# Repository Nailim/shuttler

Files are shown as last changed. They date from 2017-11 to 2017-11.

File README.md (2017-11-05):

# shuttler
Code dump for project shuttler - https://scientiatertiidimension.blogspot.com

What was project shuttler?

A project to build a mapping drone for 3D terain reconstruction which included an autopilot build for Android phones, 360° video processing, image processing, 3D pritnting, electronics design and all other neceseties when building a drone from scratch.

More info on the project blog.

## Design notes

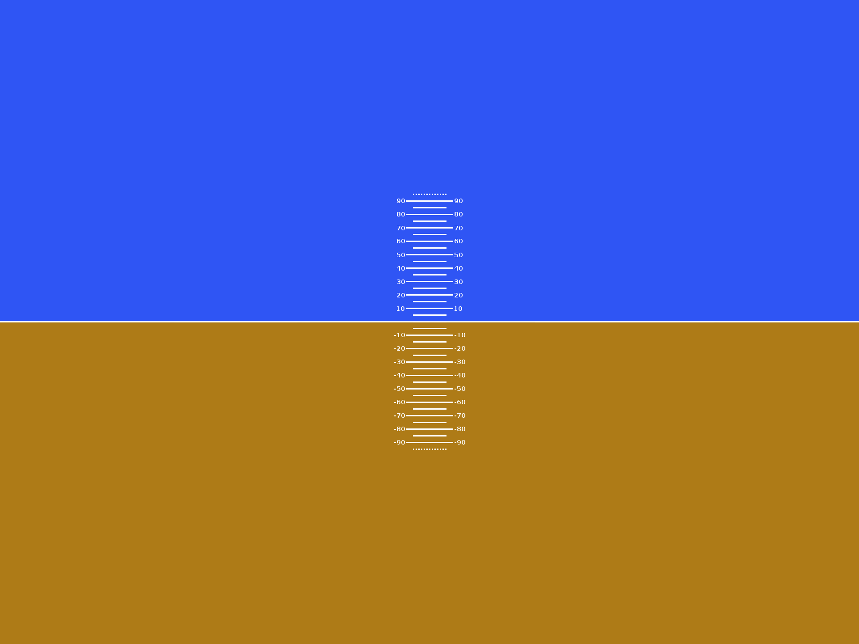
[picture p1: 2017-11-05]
Code/Python/TelemetryProcessing/telemetry2video/Attitude/resources/horizon.png

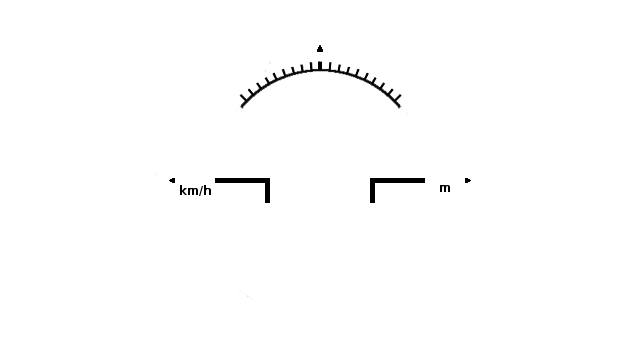
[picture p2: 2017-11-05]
Code/Python/TelemetryProcessing/telemetry2video/Attitude/resources/terrain.png

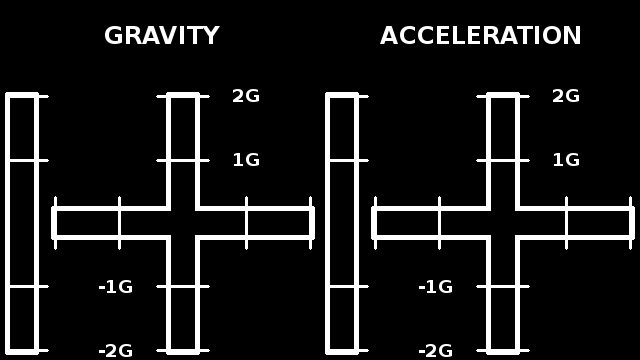
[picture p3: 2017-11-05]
Code/Python/TelemetryProcessing/telemetry2video/Acceleration/resources/controls.png

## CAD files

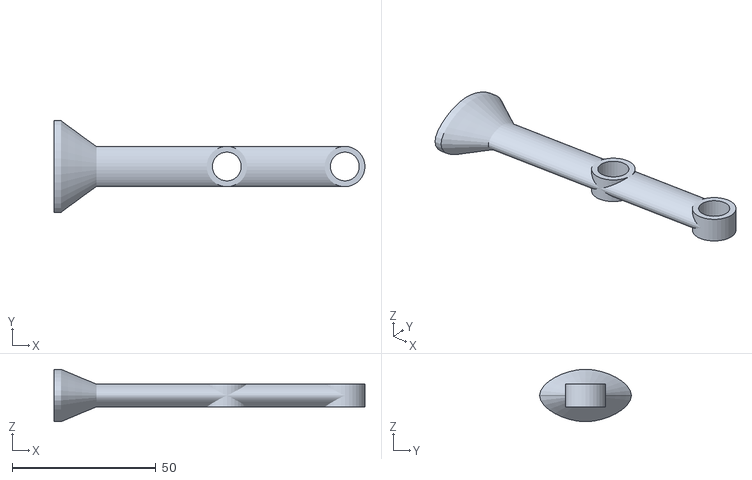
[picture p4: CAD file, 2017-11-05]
Code/Blender/CameraMountHolder/v3/CameraMountHolder_V03_repaired.stl
108.0 x 31.9 x 18.2

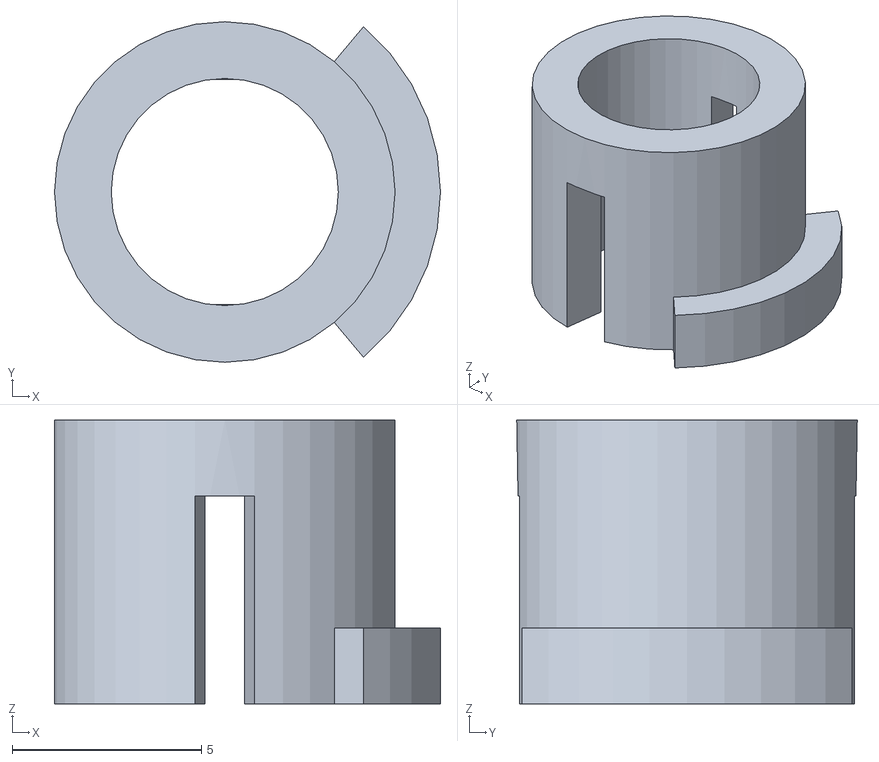
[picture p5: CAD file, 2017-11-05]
Code/Blender/PigTailJig/pigtailJig_bottom_3repared.stl
10.2 x 9.00 x 7.50

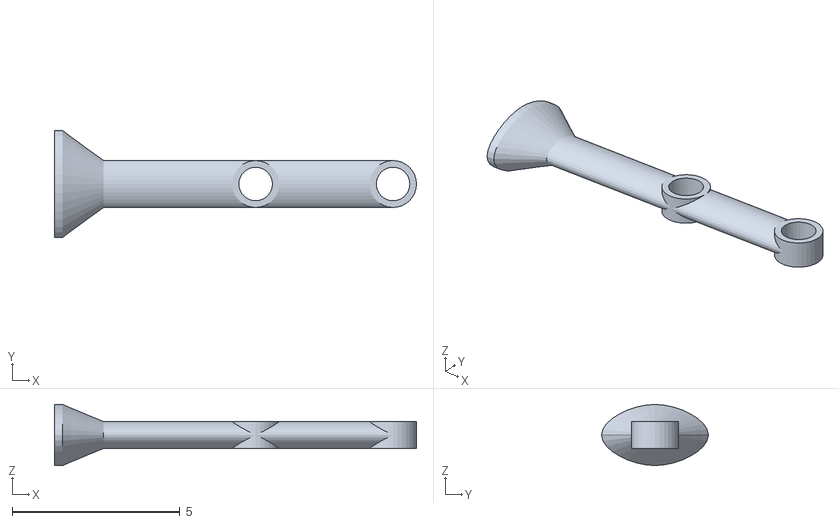
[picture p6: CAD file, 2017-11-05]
Code/Blender/CameraMountHolder/v3/CameraMountHolder_V03_raw.stl
10.8 x 3.19 x 1.82

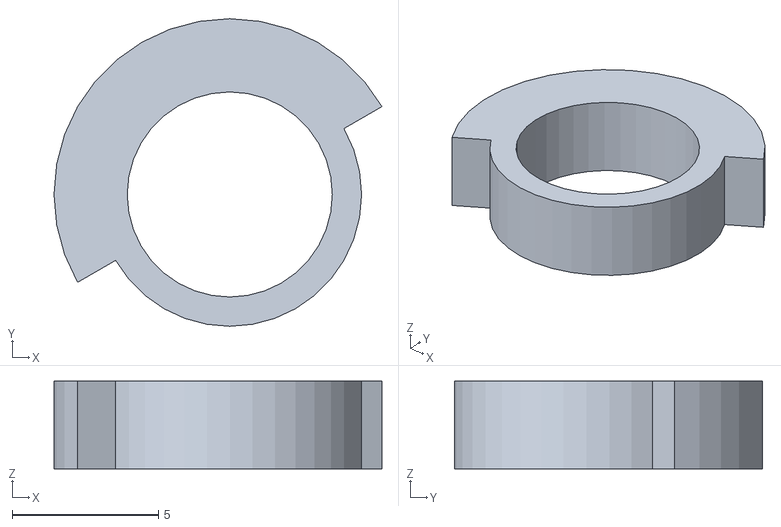
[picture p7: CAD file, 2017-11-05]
Code/Blender/PigTailJig/pigtailJig_top_3.stl
11.2 x 10.5 x 3.00

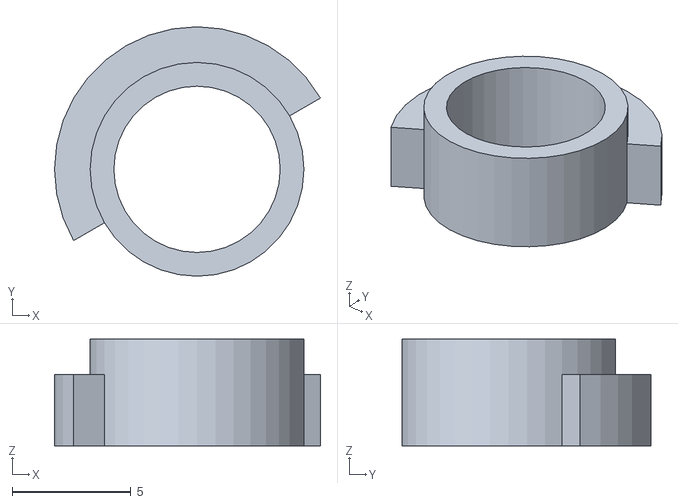
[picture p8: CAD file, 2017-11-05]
Code/Blender/PigTailJig/pigtailJig_top_2.stl
11.2 x 10.5 x 4.50

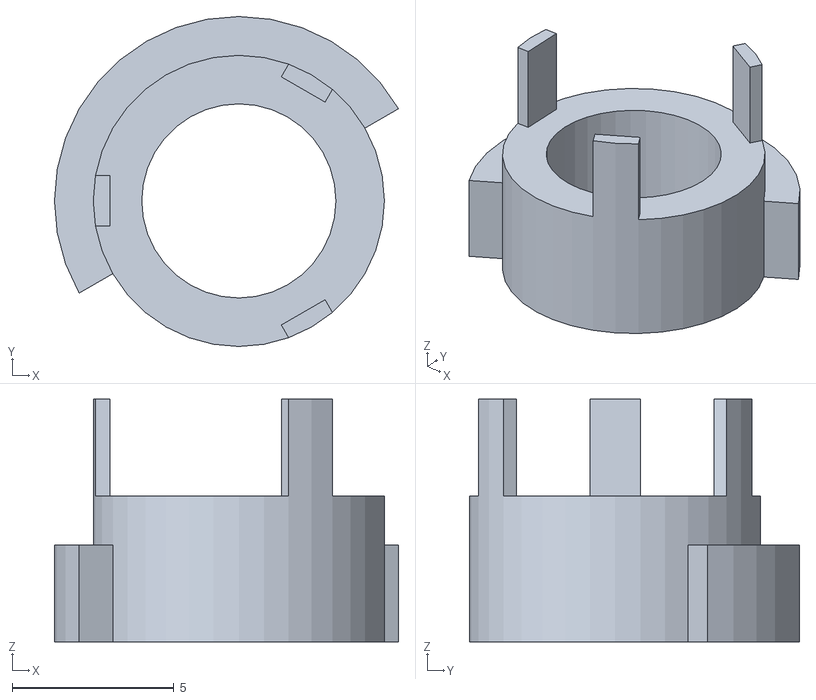
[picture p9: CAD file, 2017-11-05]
Code/Blender/PigTailJig/pigtailJig_top.stl
10.6 x 10.2 x 7.50

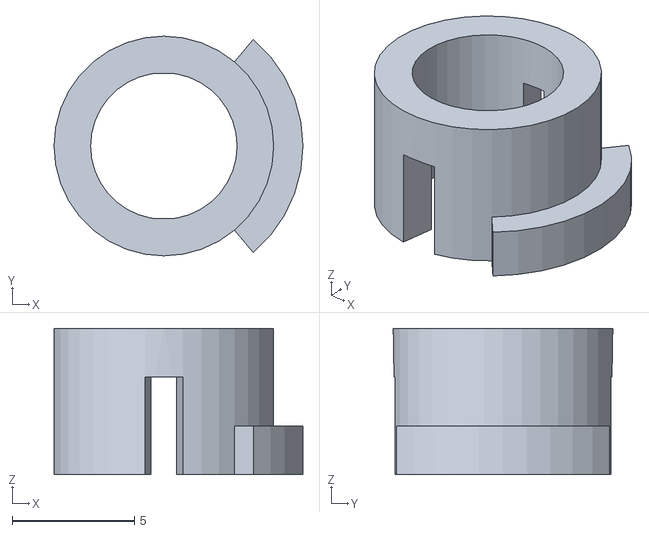
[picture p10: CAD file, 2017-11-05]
Code/Blender/PigTailJig/pigtailJig_bottom_2repared.stl
10.2 x 9.00 x 6.00

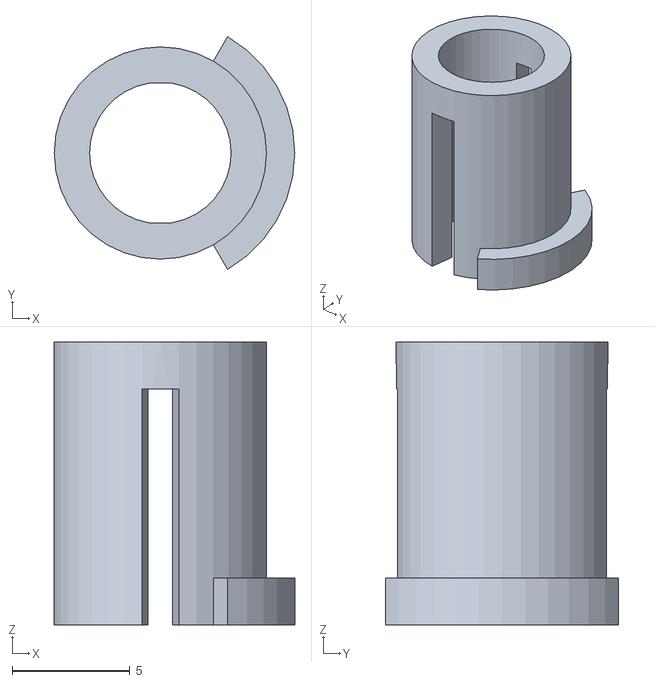
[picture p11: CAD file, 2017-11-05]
Code/Blender/PigTailJig/pigtailJig_bottom_2_repaired.stl
10.2 x 9.87 x 12.0

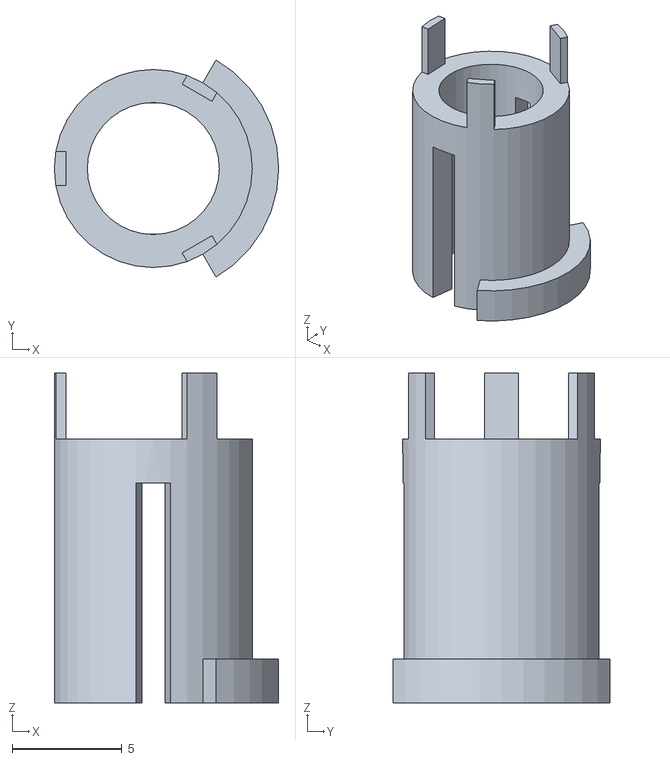
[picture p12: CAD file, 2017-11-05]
Code/Blender/PigTailJig/pigtailJig_bottom.stl
10.2 x 9.87 x 15.0

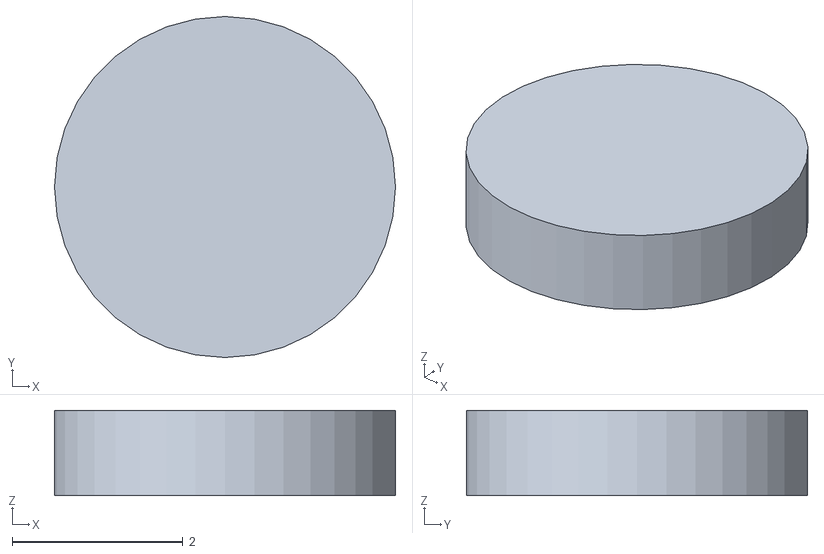
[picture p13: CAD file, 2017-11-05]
Code/Blender/PigTailJig/filler.stl
4.00 x 4.00 x 1.00

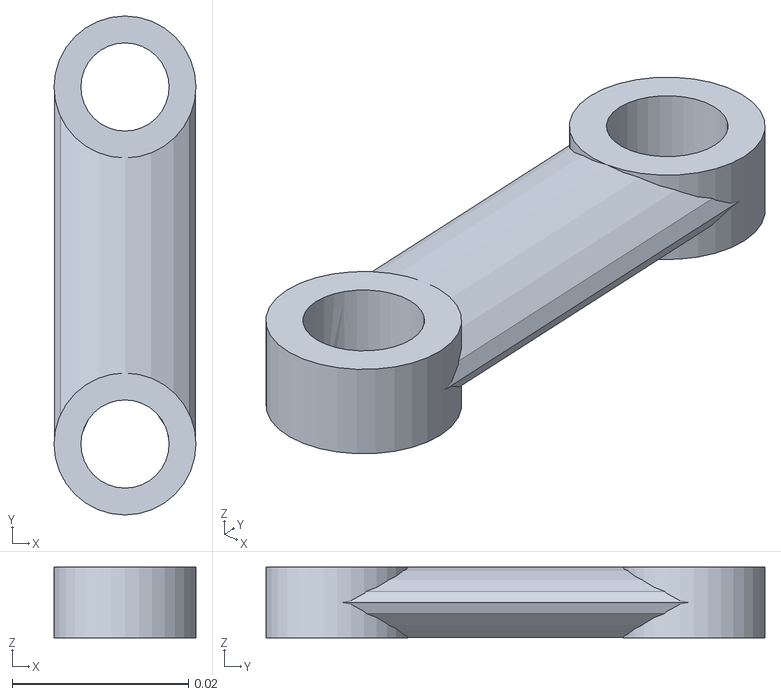
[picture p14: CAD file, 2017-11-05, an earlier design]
Code/Blender/CameraMountHolder/v1/CameraMountHolder_V01_part.stl
0.0161 x 0.0566 x 0.008

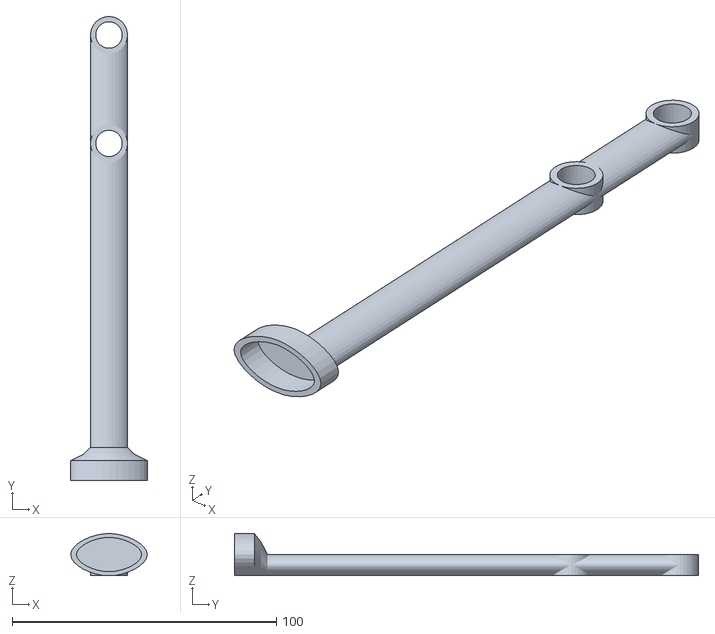
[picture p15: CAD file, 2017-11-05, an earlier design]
Code/Blender/CameraMountHolder/v2/CameraMountHolder_V02__part.stl
29.0 x 175.5 x 15.9

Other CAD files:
Code/Blender/PigTailJig/pigtailJig_top_2_repaired.stl
Code/Blender/PigTailJig/pigtailJig_top_3repared.stl
Code/Blender/PigTailJig/pigtailJig_top_repared.stl
Code/Blender/PigTailJig/pigtailJig_bottom_3.stl
Code/Blender/PigTailJig/pigtailJig_bottom_2.stl
Code/Blender/PigTailJig/pigtailJig_bottom_repared.stl
Code/Blender/CameraMountHolder/v1/CameraMountHolder_V01.blend
Code/Blender/CameraMountHolder/v1/CameraMountHolder_V01_part.blend
Code/Blender/CameraMountHolder/v1/CameraMountHolder_V01_part_ready.stl
Code/Blender/CameraMountHolder/v2/CameraMountHolder_V02.blend
Code/Blender/CameraMountHolder/v2/CameraMountHolder_V02.stl
Code/Blender/CameraMountHolder/v2/CameraMountHolder_V02_.blend
Code/Blender/CameraMountHolder/v2/CameraMountHolder_V02_.stl
Code/Blender/CameraMountHolder/v2/CameraMountHolder_V02_part.stl
Code/Blender/CameraMountHolder/v3/CameraMountHolder_V03.blend
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

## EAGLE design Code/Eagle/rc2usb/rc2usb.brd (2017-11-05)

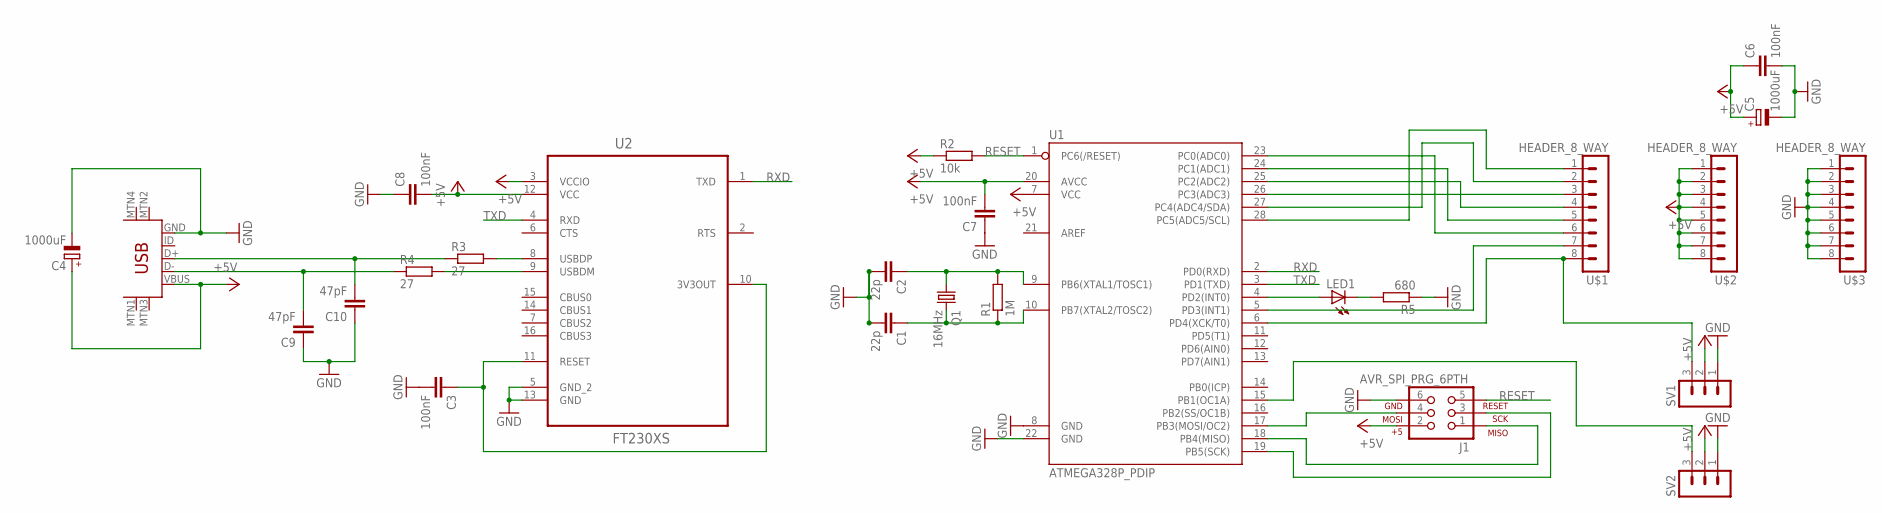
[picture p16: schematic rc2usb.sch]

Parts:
C1, C2: 22p; C025-040X050
C3, C6, C7, C8: 100nF; C025-030X050
C4, C5: 1000uF; E5-10,5
C9, C10: 47pF; C025-030X050
J1: AVR_SPI_PRG_6PTH; 2X3
LED1: LED5MM
Q1: 16MHz; HC49U70
R1: 1M; 0207/10
R2: 10k; 0207/10
R3, R4: 27; 0207/10
R5: 680; 0207/10
SV1, SV2: MA03-1
U1: ATMEGA328P_PDIP; DIL28-3
U2: FT230XS; SOP63P600X175-16N
U$1, U$2, U$3: HEADER_8_WAY
U$4: USB-MINIB-5PIN; USB-MINIB

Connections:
+5V: C4.+, C5.+, C6.1, C7.2, C8.2, J1.2, R2.1, SV1.2, SV2.2, U1.7 (VCC), U1.20 (AVCC), U2.3 (VCCIO), U2.12 (VCC), U$2.1, U$2.2, U$2.3, U$2.4, U$2.5, U$2.6, U$2.7, U$2.8, U$4.VBUS
GND: C1.2, C2.2, C3.2, C4.-, C5.-, C6.2, C7.1, C8.1, C9.1, C10.1, J1.6, R5.1, SV1.1, SV2.1, U1.8 (GND), U1.22 (GND), U2.5 (GND_2), U2.13 (GND), U$3.1, U$3.2, U$3.3, U$3.4, U$3.5, U$3.6, U$3.7, U$3.8, U$4.GND
unnamed: C2.1, Q1.1, R1.2, U1.9 (PB6(XTAL1/TOSC1))
unnamed: C1.1, Q1.2, R1.1, U1.10 (PB7(XTAL2/TOSC2))
unnamed: J1.4, U1.17 (PB3(MOSI/OC2))
unnamed: J1.1, U1.18 (PB4(MISO))
unnamed: J1.3, U1.19 (PB5(SCK))
unnamed: C10.2, R3.1, U$4.D+
unnamed: C9.2, R4.1, U$4.D-
unnamed: U1.24 (PC1(ADC1)), U$1.5
unnamed: R3.2, U2.8 (USBDP)
unnamed: LED1.A, U1.4 (PD2(INT0))
unnamed: C3.1, U2.10 (3V3OUT), U2.11 (RESET)
unnamed: R4.2, U2.9 (USBDM)
unnamed: U1.25 (PC2(ADC2)), U$1.4
unnamed: U1.26 (PC3(ADC3)), U$1.3
unnamed: U1.23 (PC0(ADC0)), U$1.6
unnamed: U1.27 (PC4(ADC4/SDA)), U$1.2
unnamed: U1.28 (PC5(ADC5/SCL)), U$1.1
unnamed: U1.5 (PD3(INT1)), U$1.7
unnamed: SV1.3, U1.6 (PD4(XCK/T0)), U$1.8
unnamed: SV2.3, U1.15 (PB1(OC1A))
unnamed: LED1.K (C), R5.2
RESET: J1.5, R2.2, U1.1 (PC6(/RESET))
RXD: U1.2 (PD0(RXD)), U2.1 (TXD)
TXD: U1.3 (PD1(TXD)), U2.4 (RXD)

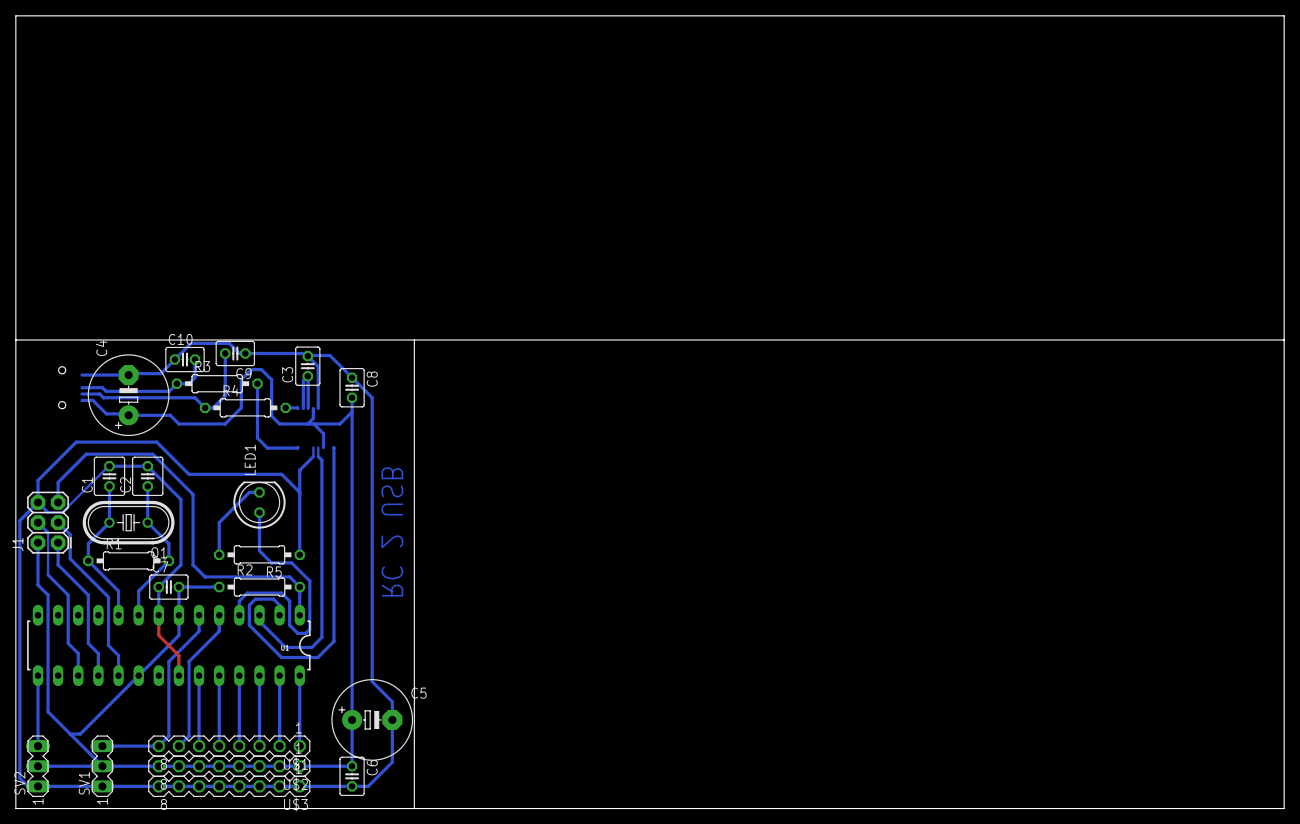
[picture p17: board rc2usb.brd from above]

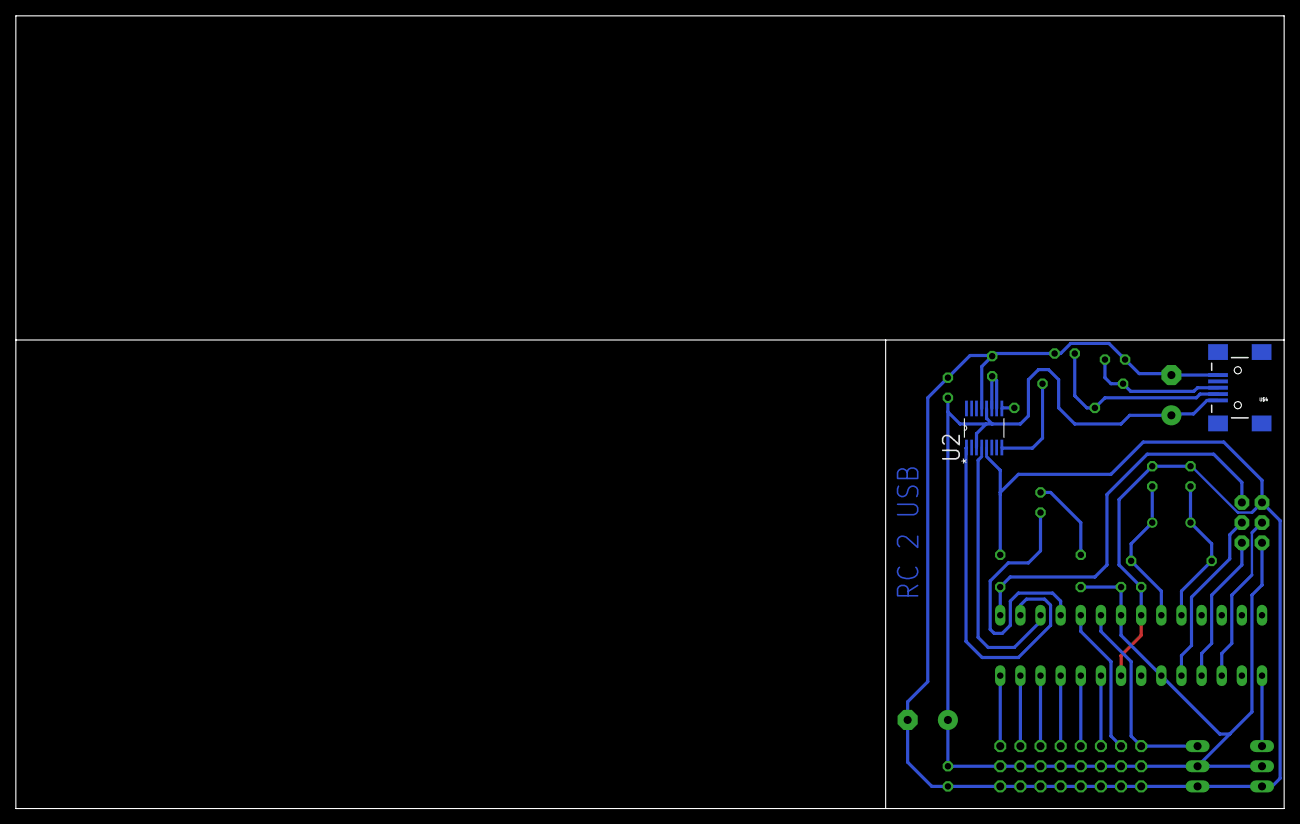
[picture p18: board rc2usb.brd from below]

Board: 2 copper layers, 160.0 x 100.0 mm, 26 parts (2 on the bottom side), 26 nets.

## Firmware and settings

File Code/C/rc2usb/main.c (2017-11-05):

#include <avr/io.h>
#include <util/delay.h>
#include <avr/interrupt.h>
#include <stdlib.h>

// USART definitions
#define BAUD 57600
#define FOSC 20000000			// clock Speed
#define MYUBRR FOSC/16/BAUD-1

// global variables
volatile unsigned char port_c_last = 0x00;		// pin change interrupts PC0-5
volatile unsigned char port_c_change = 0x00;	// pin change interrupts PC0-5
volatile unsigned char port_d_last = 0x00;		// pin change interrupts PD3-4
volatile unsigned char port_d_change = 0x00;	// pin change interrupts PD3-4

volatile unsigned short timer_temp = 0x0000;
volatile unsigned short timer_temp_result[8] = {0x0EA6, 0x0EA6, 0x0EA6, 0x0EA6, 0x0EA6, 0x0EA6, 0x0EA6, 0x0EA6};	// 0x0EA6=3750 - after conversion the output is 0
volatile unsigned short timer_temp_storage[8] = {0x0000, 0x0000, 0x0000, 0x0000, 0x0000, 0x0000, 0x0000, 0x0000};	// storage like any other

volatile unsigned char counter_low = 0x00;
volatile unsigned char counter_high = 0x00;
volatile unsigned short temp_storage = 0x0000;

volatile float data_out = 0.0;					// output data in the right format for flightgear to parse
char buffer_out[10];							// flightgear likes strings
unsigned char buffer_out_pos;					// char by char eaquals string

// USART init
void USART_Init( unsigned int ubrr) {
	// set baud rate
	UBRR0H = (unsigned char)(ubrr>>8);
	UBRR0L = (unsigned char)ubrr;

	// enable receiver and transmitter
	UCSR0B = (1<<RXEN0)|(1<<TXEN0);
	
	// set frame format: 8data, 2stop bit
	UCSR0C = (1<<USBS0)|(3<<UCSZ00);
}

// USART transmit
void USART_Transmit( unsigned char data ) {
	// wait for empty transmit buffer
	while ( !( UCSR0A & (1<<UDRE0)) );
	
	// put data into buffer, sends the data
	UDR0 = data;
}

// pin change interrupt alias
ISR(PCINT2_vect, ISR_ALIASOF(PCINT1_vect));

// pin change interrupt
ISR(PCINT1_vect) {
	// get the timer, get the timer NOW!
	timer_temp = TCNT1;	
	
	// check which pin triggerd the interrupt
	port_c_change = (PINC & PCMSK1) ^ port_c_last;
	port_d_change = (PIND & PCMSK2) ^ port_d_last;
	port_c_last = (PINC & PCMSK1);
	port_d_last = (PIND & PCMSK2);
	
	// find and service the apropriate pins
	if (port_c_change & 0x20) {			// channel 1 (PC5 - PCINT 13 - PCMSK1 bit 5)
		if (port_c_last & 0x20) {		// low to hight
			timer_temp_storage[0] = timer_temp;
		}
		else {							// high to low
			if (timer_temp >= timer_temp_storage[0]) {
				timer_temp_result[0] = timer_temp - timer_temp_storage[0];
			}
			else {
				timer_temp_result[0] = (ICR1 - timer_temp_storage[0]) + timer_temp;
			}
		}
	}
	if (port_c_change & 0x10) {			// channel 2 (PC4 - PCINT 12 - PCMSK1 bit 4)
		if (port_c_last & 0x10) {		// low to hight
			timer_temp_storage[1] = timer_temp;
		}
		else {							// high to low
			if (timer_temp >= timer_temp_storage[1]) {
				timer_temp_result[1] = timer_temp - timer_temp_storage[1];
			}
			else {
				timer_temp_result[1] = (ICR1 - timer_temp_storage[1]) + timer_temp;
			}
		}
	}
	if (port_c_change & 0x08) {			// channel 3 (PC3 - PCINT 11 - PCMSK1 bit 3)
		if (port_c_last & 0x08) {		// low to hight
			timer_temp_storage[2] = timer_temp;
		}
		else {							// high to low			
			if (timer_temp >= timer_temp_storage[2]) {
				timer_temp_result[2] = timer_temp - timer_temp_storage[2];
			}
			else {
				timer_temp_result[2] = (ICR1 - timer_temp_storage[2]) + timer_temp;
			}
		}
	}
	if (port_c_change & 0x04) {			// channel 4 (PC2 - PCINT 10 - PCMSK1 bit 2)
		if (port_c_last & 0x04) {		// low to hight
			timer_temp_storage[3] = timer_temp;
		}
		else {							// high to low			
			if (timer_temp >= timer_temp_storage[3]) {
				timer_temp_result[3] = timer_temp - timer_temp_storage[3];
			}
			else {
				timer_temp_result[3] = (ICR1 - timer_temp_storage[3]) + timer_temp;
			}
		}
	}
	if (port_c_change & 0x02) {			// channel 5 (PC1 - PCINT 9 - PCMSK1 bit 1)
		if (port_c_last & 0x02) {		// low to hight
			timer_temp_storage[4] = timer_temp;
		}
		else {							// high to low			
			if (timer_temp >= timer_temp_storage[4]) {
				timer_temp_result[4] = timer_temp - timer_temp_storage[4];
			}
			else {
				timer_temp_result[4] = (ICR1 - timer_temp_storage[4]) + timer_temp;
			}
		}
	}
	if (port_c_change & 0x01) {			// channel 6 (PC0 - PCINT 8 - PCMSK1 bit 0)
		if (port_c_last & 0x01) {		// low to hight
			timer_temp_storage[5] = timer_temp;
		}
		else {							// high to low
			if (timer_temp >= timer_temp_storage[5]) {
				timer_temp_result[5] = timer_temp - timer_temp_storage[5];
			}
			else {
				timer_temp_result[5] = (ICR1 - timer_temp_storage[5]) + timer_temp;
			}
		}
	}
	if (port_d_change & 0x08) {			// channel 7 (PD3 - PCINT 19 - PCMSK2 bit 3)
		if (port_d_last & 0x08) {		// low to hight
			timer_temp_storage[6] = timer_temp;
		}
		else {							// high to low
			if (timer_temp >= timer_temp_storage[6]) {
				timer_temp_result[6] = timer_temp - timer_temp_storage[6];
			}
			else {
				timer_temp_result[6] = (ICR1 - timer_temp_storage[6]) + timer_temp;
			}
		}
	}
	if (port_d_change & 0x10) {			// channel 8 (PD4 - PCINT 20 - PCMSK2 bit 4)
		if (port_d_last & 0x10) {		// low to hight
			timer_temp_storage[7] = timer_temp;
		}
		else {							// high to low			
			if (timer_temp >= timer_temp_storage[7]) {
				timer_temp_result[7] = timer_temp - timer_temp_storage[7];
			}
			else {
				timer_temp_result[7] = (ICR1 - timer_temp_storage[7]) + timer_temp;
			}
		}
	}	
}

ISR(TIMER1_COMPB_vect) {
	// turn off other interrupts (servo duty cycle is 50Hz, so we get at least every other one while we're not sending)
	cli();	// optional - works without, but why waste cycles reading new servo state if we read it at least once more before we send it
	
	// update the conter, update the counter now
	counter_low++;
	
	// run 25 times per second - transmit and more
	if (counter_low >= 2) {
		// transmmit - the slowest part of them all (one by one, divide and convert)
		temp_storage = timer_temp_result[0];				// get the last known servo state, so it's not overwritten if we got an interrupt in an interrupt
		data_out = (temp_storage / 1250.0) - 3.0 ;			// formula for converting 2500 to 5000 counter cycles in to -1.0 to 1.0 range (flightgear likes)
		dtostrf(data_out, 0, 2, buffer_out);				// flightgear likes strings, converting float to string (2 decimal precisin)
		buffer_out_pos = 0;									// char in string counter
		while (buffer_out[buffer_out_pos] != '\0') {		// send data
			USART_Transmit(buffer_out[buffer_out_pos]);
			buffer_out_pos++;	
		}
		USART_Transmit('\t');								// send delimiter
		
		temp_storage = timer_temp_result[1];
		data_out = (temp_storage / 1250.0) - 3.0 ;
		dtostrf(data_out, 0, 2, buffer_out);
		buffer_out_pos = 0;
		while (buffer_out[buffer_out_pos] != '\0') {
			USART_Transmit(buffer_out[buffer_out_pos]);
			buffer_out_pos++;	
		}
		USART_Transmit('\t');
		
		temp_storage = timer_temp_result[2];
		data_out = (temp_storage / 1250.0) - 3.0 ;
		dtostrf(data_out, 0, 2, buffer_out);
		buffer_out_pos = 0;
		while (buffer_out[buffer_out_pos] != '\0') {
			USART_Transmit(buffer_out[buffer_out_pos]);
			buffer_out_pos++;	
		}
		USART_Transmit('\t');
		
		temp_storage = timer_temp_result[3];
		data_out = (temp_storage / 1250.0) - 3.0 ;
		dtostrf(data_out, 0, 2, buffer_out);
		buffer_out_pos = 0;
		while (buffer_out[buffer_out_pos] != '\0') {
			USART_Transmit(buffer_out[buffer_out_pos]);
			buffer_out_pos++;	
		}
		USART_Transmit('\t');
		
		temp_storage = timer_temp_result[4];
		data_out = (temp_storage / 1250.0) - 3.0 ;
		dtostrf(data_out, 0, 2, buffer_out);
		buffer_out_pos = 0;
		while (buffer_out[buffer_out_pos] != '\0') {
			USART_Transmit(buffer_out[buffer_out_pos]);
			buffer_out_pos++;	
		}
		USART_Transmit('\t');
		
		temp_storage = timer_temp_result[5];
		data_out = (temp_storage / 1250.0) - 3.0 ;
		dtostrf(data_out, 0, 2, buffer_out);
		buffer_out_pos = 0;
		while (buffer_out[buffer_out_pos] != '\0') {
			USART_Transmit(buffer_out[buffer_out_pos]);
			buffer_out_pos++;	
		}
		USART_Transmit('\t');
		
		temp_storage = timer_temp_result[6];
		data_out = (temp_storage / 1250.0) - 3.0 ;
		dtostrf(data_out, 0, 2, buffer_out);
		buffer_out_pos = 0;
		while (buffer_out[buffer_out_pos] != '\0') {
			USART_Transmit(buffer_out[buffer_out_pos]);
			buffer_out_pos++;	
		}
		USART_Transmit('\t');
		
		temp_storage = timer_temp_result[7];
		data_out = (temp_storage / 1250.0) - 3.0 ;
		dtostrf(data_out, 0, 2, buffer_out);
		buffer_out_pos = 0;
		while (buffer_out[buffer_out_pos] != '\0') {
			USART_Transmit(buffer_out[buffer_out_pos]);
			buffer_out_pos++;	
		}
		USART_Transmit('\n');
		
		counter_low = 0;
		counter_high++;
		
		// run 1 time per second - set servo position and LED status
		if (counter_high == 25) {
			OCR1A = (2500*1.5);		// servo center position
			PORTD |= 0x04;			// LED on
		}
		else if (counter_high == 50) {
			OCR1A = (2500*1.0);		// servo left position
			PORTD &= ~0x04;			// LED off
		}
		else if (counter_high == 75) {
			OCR1A = (2500*1.5);		// servo center position
			PORTD |= 0x04;			// LED on
		}
		else if (counter_high == 100) {
			OCR1A = (2500*2.0);		// servo right position
			PORTD &= ~0x04;			// LED off
			counter_high = 0;		// restart the cycle
		}
		
	}
	// enable back all interrupts
	sei();	// optional - use if interrupts disabled at the beginning
}

int main(void) {
	// set PD2 as output - LED
	DDRD |= 0x04;
	PORTD &= ~0x04;		// LED (PD2) off
	
	// set PB1 as output - PWM
	DDRB |= 0x02;
	
	// set PC0-5 (PCI1) & PD3-4 (PCI2) as input - PIN CHANGE INTERRUPT
	DDRC &= ~0x3F;
	DDRD &= ~0x19;	// includes the RX to FT230X
	
	// set internal pull up resistors
	PORTC |= 0x3F;
	PORTD |= 0x19;
	
	
	// init USART
	USART_Init(MYUBRR);
	
	// set Timer/Counter1 with PWM
	TCCR1A |= 1<<WGM11;					// set Waveform Generation Mode to 14 (fast PWM - ICR1)
	TCCR1B |= 1<<WGM12 | 1<<WGM13;		// set Waveform Generation Mode to 14 (fast PWM - ICR1)
	//TCCR1A |= 1<<COM1A1 | 1<<COM1A0;	// set inverted mode (starts at 0, jumps to 1 when OCR1A is reached)
	TCCR1A |= 1<<COM1A1;				// set non-inverted mode (starts at 1, jumps to 0 when OCR1A is reached)
	TCCR1B |= 1<<CS11;					// set prescaler to 8 (50Hz duty cycle for servo - ((20000000/8)/50) = 50000)	
	ICR1 = 49999;						// set the Input Capture Register for 50Hz duty cycle (0-49999)
	// set Timer/Counter1 with interrupt
	TIMSK1 |= 1<<OCIE1B;				// set interrupt on CTC
	OCR1B = 49999;						// set Output Compare Register for 50Hz (once every 20ms)
	
	// set PIN CHANGE INTERRUPT
	PCICR |= 1<<PCIE1 | 1<<PCIE2;		// enable pin change interrupts PC0-5 (PCI1) & PD3-4 (PCI2)
	PCMSK1 |= 1<<PCINT13 | 1<<PCINT12 | 1<<PCINT11 | 1<<PCINT10 | 1<<PCINT9 | 1<<PCINT8;	// enable pins PC0-5 (PCI1)
	PCMSK2 |= 1<<PCINT20 | 1<<PCINT19;														// enable pins PD3-4 (PCI2)
	
	// enable interrups
	sei();	
	
	// do nothing and repeat - interrupts do all the work
	for(;;);
}

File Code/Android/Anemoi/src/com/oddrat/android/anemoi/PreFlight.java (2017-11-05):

package com.oddrat.android.anemoi;

import java.io.File;
import java.io.FileNotFoundException;
import java.io.FileOutputStream;
import java.io.IOException;
import java.io.InputStream;
import java.io.OutputStream;
import java.util.ArrayList;
import java.util.List;

import android.app.Activity;
import android.app.AlertDialog;
import android.app.Dialog;
import android.content.DialogInterface;
import android.content.Intent;
import android.content.SharedPreferences;
import android.content.pm.ActivityInfo;
import android.graphics.PorterDuff;
import android.net.Uri;
import android.os.Bundle;
import android.os.Environment;
import android.util.Log;
import android.view.View;
import android.view.View.OnClickListener;
import android.webkit.MimeTypeMap;
import android.widget.AdapterView;
import android.widget.AdapterView.OnItemClickListener;
import android.widget.AdapterView.OnItemSelectedListener;
import android.widget.ArrayAdapter;
import android.widget.Button;
import android.widget.CompoundButton;
import android.widget.CompoundButton.OnCheckedChangeListener;
import android.widget.EditText;
import android.widget.LinearLayout;
import android.widget.ListView;
import android.widget.Spinner;
import android.widget.Switch;

public class PreFlight extends Activity {
	
	private static final String PREF_NAME = "Anemoi";
	
	public final static String MESSAGE_ACTIVITY = "com.oddrat.android.anemoi.MESSAGE";
	public final static String MESSAGE_SETTINGS_AUTOPILOT = "settings_autopilot";
	public final static String MESSAGE_SETTINGS_COPILOT = "settings_copilot";
	public final static String MESSAGE_SETTINGS_AUTOPILOT_TYPE = "settings_autopilot_type";
	public final static String MESSAGE_SETTINGS_FLIGHTGEAR_ADDRESS = "settings_flightgear_address";
	public final static String MESSAGE_SETTINGS_FLIGHTGEAR_PORT = "settings_flightgear_port";
	public final static String MESSAGE_SETTINGS_MISSION_FILE = "settings_mission_file";
	public final static String MESSAGE_SETTINGS_DATA_PATH = "settings_data_path";
	
	private static final int DIALOG_FLIGHTGEAR_ADDRESS = 0;
	private static final int DIALOG_FLIGHTGEAR_PORT = 1;
	private static final int DIALOG_ANEMOI_PATH = 2;
	
	private static final int ACTIVITY_MISSION_FILE = 0;
	//private static final int ACTIVITY_DATA_PATH = 1;		// replaced with custom dialog
	
	private ArrayAdapter<?> xAdaptor;
	
	private Switch switch_settings_autopilot;
	private Switch switch_settings_copilot;
	
	private Spinner spinner_settings_autopilot_type;
	
	private LinearLayout linearlayout_settings_autopilot;
	private LinearLayout linearlayout_settings_copilot;
	
	private LinearLayout linearlayout_settings_autopilot_flightgear;
	
	private Button button_settings_autopilot_data_path;
	private Button button_settings_autopilot_data_path_check;
	
	private Button button_settings_autopilot_flightgear_address;
	private Button button_settings_autopilot_flightgear_port;
	
	private Button button_settings_autopilot_mission_file;
	
	private Button button_settings_folder_up;
	private Button button_settings_folder_select;
	
	private File root;
	private File curFolder;
	
	private ListView dialog_folder_listview;
	
	private List<String> fileList = new ArrayList<String>();
	
	
	private String data_flightgear_address;
	private String data_flightgear_port;
	private String data_mission_file;
	private String data_data_path;
	
    @Override
    public void onCreate(Bundle savedInstanceState) {
        super.onCreate(savedInstanceState);
        
        // set screen
        setRequestedOrientation(ActivityInfo.SCREEN_ORIENTATION_PORTRAIT);
        //requestWindowFeature(Window.FEATURE_NO_TITLE);
        this.setTitle("pre-flight preparation");
        
        // set view
        setContentView(R.layout.activity_preflight);
        
        // assign handlers
        switch_settings_autopilot = (Switch) findViewById(R.id.switch_settings_autopilot);
        switch_settings_autopilot.setOnCheckedChangeListener(new OnCheckedChangeListener() {
			
			public void onCheckedChanged(CompoundButton buttonView, boolean isChecked) {
				if (switch_settings_autopilot.isChecked()) {
		        	linearlayout_settings_autopilot.setVisibility(View.VISIBLE);
		        } else {
		        	linearlayout_settings_autopilot.setVisibility(View.GONE);
		        }
				
			}
		});
        
        switch_settings_copilot = (Switch) findViewById(R.id.switch_settings_copilot);
        switch_settings_copilot.setOnCheckedChangeListener(new OnCheckedChangeListener() {
			
			public void onCheckedChanged(CompoundButton buttonView, boolean isChecked) {
				if (switch_settings_copilot.isChecked()) {
		        	linearlayout_settings_copilot.setVisibility(View.VISIBLE);
		        } else {
		        	linearlayout_settings_copilot.setVisibility(View.GONE);
		        }
				
			}
		});
        
        spinner_settings_autopilot_type = (Spinner) findViewById(R.id.spinner_settings_autopilot_type);
        xAdaptor = ArrayAdapter.createFromResource(this, R.array.array_autopilot_type, android.R.layout.simple_spinner_item);
		xAdaptor.setDropDownViewResource(android.R.layout.simple_spinner_dropdown_item);
		spinner_settings_autopilot_type.setAdapter(xAdaptor);
		spinner_settings_autopilot_type.setOnItemSelectedListener(new OnItemSelectedListener() {

			public void onItemSelected(AdapterView<?> arg0, View arg1, int arg2, long arg3) {
				// TODO Auto-generated method stub
				if (spinner_settings_autopilot_type.getSelectedItemPosition() == 0) {
					linearlayout_settings_autopilot_flightgear.setVisibility(View.GONE);
		        }
		        else {
		        	linearlayout_settings_autopilot_flightgear.setVisibility(View.VISIBLE);
		        }
			}
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

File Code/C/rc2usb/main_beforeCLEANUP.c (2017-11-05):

#include <avr/io.h>
#include <util/delay.h>
#include <avr/interrupt.h>

// USART definitions
#define BAUD 9600
#define FOSC 20000000			// clock Speed
#define MYUBRR FOSC/16/BAUD-1

// global variables
volatile unsigned char port_c_last = 0x00;		// pin change interrupts PC0-5
volatile unsigned char port_c_change = 0x00;	// pin change interrupts PC0-5
volatile unsigned char port_d_last = 0x00;		// pin change interrupts PD3-4
volatile unsigned char port_d_change = 0x00;	// pin change interrupts PD3-4

//volatile unsigned char timer_temp_low = 0x00;
//volatile unsigned char timer_temp_high = 0x00;
volatile unsigned short timer_temp = 0x0000;
volatile unsigned short timer_temp_result = 0x0000;
volatile unsigned short timer_temp_storage[8] = {0x0000, 0x0000, 0x0000, 0x0000, 0x0000, 0x0000, 0x0000, 0x0000};

volatile unsigned char counter_low = 0x00;
volatile unsigned char counter_high = 0x00;

// USART init
void USART_Init( unsigned int ubrr) {
	// set baud rate
	UBRR0H = (unsigned char)(ubrr>>8);
	UBRR0L = (unsigned char)ubrr;

	// enable receiver and transmitter
	UCSR0B = (1<<RXEN0)|(1<<TXEN0);
	
	// set frame format: 8data, 2stop bit
	UCSR0C = (1<<USBS0)|(3<<UCSZ00);
}

// USART transmit
void USART_Transmit( unsigned char data ) {
	// wait for empty transmit buffer
	while ( !( UCSR0A & (1<<UDRE0)) );
	
	// put data into buffer, sends the data
	UDR0 = data;
}

// pin change interrupt alias
ISR(PCINT2_vect, ISR_ALIASOF(PCINT1_vect));

// pin change interrupt
ISR(PCINT1_vect) {
	// get the timer, get he timer NOW!
	//timer_temp_low = TCNT1L;
	//timer_temp_high = TCNT1H;
	timer_temp = TCNT1;
	
	// check which pin triggerd the interrupt
	port_c_change = (PINC & PCMSK1) ^ port_c_last;
	port_d_change = (PIND & PCMSK2) ^ port_d_last;
	
	// find and service the apropriate pins
	if (port_c_change & 0x20) {			// channel 1 (PC5 - PCINT 13 - PCMSK1 bit 5)
		//USART_Transmit('a');
		if (PINC & 0x20) {				// low to hight
			//USART_Transmit('+');
			//timer_temp_storage[0] = (timer_temp_high<<8);
			//timer_temp_storage[0] = timer_temp_storage[0] + timer_temp_low;
			timer_temp_storage[0] = timer_temp;
		}
		else {							// high to low
			//USART_Transmit('-');
			//timer_temp = (timer_temp_high<<8);
			//timer_temp = timer_temp + timer_temp_low;
			
			timer_temp_result = timer_temp - timer_temp_storage[0];
			USART_Transmit(timer_temp_result>>8);
			USART_Transmit(timer_temp_result);
		}
	}
	else if (port_c_change & 0x10) {	// channel 2 (PC4 - PCINT 12 - PCMSK1 bit 4)
		//USART_Transmit('b');
		if (PINC & 0x10) {				// low to hight
			//USART_Transmit('+');
			//timer_temp_storage[1] = (timer_temp_high<<8);
			//timer_temp_storage[1] = timer_temp_storage[1] + timer_temp_low;
			timer_temp_storage[1] = timer_temp;
		}
		else {							// high to low
			//USART_Transmit('-');
			//timer_temp = (timer_temp_high<<8);
			//timer_temp = timer_temp + timer_temp_low;
			
			timer_temp_result = timer_temp - timer_temp_storage[1];
			USART_Transmit(timer_temp_result>>8);
			USART_Transmit(timer_temp_result);
		}
	}
	else if (port_c_change & 0x08) {	// channel 3 (PC3 - PCINT 11 - PCMSK1 bit 3)
		//USART_Transmit('c');
		if (PINC & 0x08) {				// low to hight
			//USART_Transmit('+');
			//timer_temp_storage[2] = (timer_temp_high<<8);
			//timer_temp_storage[2] = timer_temp_storage[2] + timer_temp_low;
			timer_temp_storage[2] = timer_temp;
		}
		else {							// high to low
			//USART_Transmit('-');
			//timer_temp = (timer_temp_high<<8);
			//timer_temp = timer_temp + timer_temp_low;
			
			timer_temp_result = timer_temp - timer_temp_storage[2];
			USART_Transmit(timer_temp_result>>8);
			USART_Transmit(timer_temp_result);
		}
	}
	else if (port_c_change & 0x04) {	// channel 4 (PC2 - PCINT 10 - PCMSK1 bit 2)
		//USART_Transmit('d');
		if (PINC & 0x04) {				// low to hight
			//USART_Transmit('+');
			//timer_temp_storage[3] = (timer_temp_high<<8);
			//timer_temp_storage[3] = timer_temp_storage[3] + timer_temp_low;
			timer_temp_storage[3] = timer_temp;
		}
		else {							// high to low
			//USART_Transmit('-');
			//timer_temp = (timer_temp_high<<8);
			//timer_temp = timer_temp + timer_temp_low;
			
			timer_temp_result = timer_temp - timer_temp_storage[3];
			USART_Transmit(timer_temp_result>>8);
			USART_Transmit(timer_temp_result);
		}
	}
	else if (port_c_change & 0x02) {	// channel 5 (PC1 - PCINT 9 - PCMSK1 bit 1)
		//USART_Transmit('e');
		if (PINC & 0x02) {				// low to hight
			//USART_Transmit('+');
			//timer_temp_storage[4] = (timer_temp_high<<8);
			//timer_temp_storage[4] = timer_temp_storage[4] + timer_temp_low;
			timer_temp_storage[4] = timer_temp;
		}
		else {							// high to low
			//USART_Transmit('-');
			//timer_temp = (timer_temp_high<<8);
			//timer_temp = timer_temp + timer_temp_low;
			
			timer_temp_result = timer_temp - timer_temp_storage[4];
			USART_Transmit(timer_temp_result>>8);
			USART_Transmit(timer_temp_result);
		}
	}
	else if (port_c_change & 0x01) {	// channel 6 (PC0 - PCINT 8 - PCMSK1 bit 0)
		//USART_Transmit('f');
		if (PINC & 0x01) {				// low to hight
			//USART_Transmit('+');
			//timer_temp_storage[5] = (timer_temp_high<<8);
			//timer_temp_storage[5] = timer_temp_storage[5] + timer_temp_low;
			timer_temp_storage[5] = timer_temp;
		}
		else {							// high to low
			//USART_Transmit('-');
			//timer_temp = (timer_temp_high<<8);
			//timer_temp = timer_temp + timer_temp_low;
			
			timer_temp_result = timer_temp - timer_temp_storage[5];
			USART_Transmit(timer_temp_result>>8);
			USART_Transmit(timer_temp_result);
		}
	}
	else if (port_d_change & 0x08) {	// channel 7 (PD3 - PCINT 19 - PCMSK2 bit 3)
		//USART_Transmit('g');
		if (PIND & 0x08) {				// low to hight
			//USART_Transmit('+');
			//timer_temp_storage[6] = (timer_temp_high<<8);
			//timer_temp_storage[6] = timer_temp_storage[6] + timer_temp_low;
			timer_temp_storage[6] = timer_temp;
		}
		else {							// high to low
			//USART_Transmit('-');
			//timer_temp = (timer_temp_high<<8);
			//timer_temp = timer_temp + timer_temp_low;
			
			timer_temp_result = timer_temp - timer_temp_storage[6];
			USART_Transmit(timer_temp_result>>8);
			USART_Transmit(timer_temp_result);
		}
	}
	else if (port_d_change & 0x10) {	// channel 8 (PD4 - PCINT 20 - PCMSK2 bit 4)
		//USART_Transmit('h');
		if (PIND & 0x10) {				// low to hight
			//USART_Transmit('+');
			//timer_temp_storage[7] = (timer_temp_high<<8);
			//timer_temp_storage[7] = timer_temp_storage[7] + timer_temp_low;
			timer_temp_storage[7] = timer_temp;
		}
		else {							// high to low
			//USART_Transmit('-');
			//timer_temp = (timer_temp_high<<8);
			//timer_temp = timer_temp + timer_temp_low;
			
			timer_temp_result = timer_temp - timer_temp_storage[7];
			USART_Transmit(timer_temp_result>>8);
			USART_Transmit(timer_temp_result);
		}
	}
	//if (PINC & 0x20) {			// channel 1 (PC5)
	//	
	//}
	
	
	// save port state
	port_c_last = (PINC & PCMSK1);
	port_d_last = (PIND & PCMSK2);
	
	//USART_Transmit('p');
	//USART_Transmit('p');
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

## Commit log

2017-11-05 Add project source sode.
    [CameraMountHolder_V01.blend, CameraMountHolder_V01_part.blend, CameraMountHolder_V01_part.stl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]
2017-11-05 Add required directory for autopilot telemetry processing with example.
    [gps.csv, ori.csv, pidPITCH.csv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]

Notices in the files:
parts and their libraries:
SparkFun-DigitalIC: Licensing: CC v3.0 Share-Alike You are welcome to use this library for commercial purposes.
